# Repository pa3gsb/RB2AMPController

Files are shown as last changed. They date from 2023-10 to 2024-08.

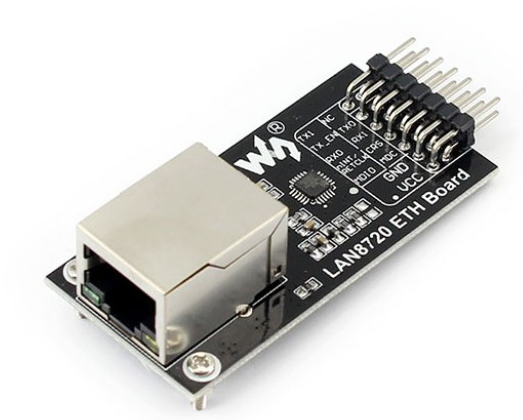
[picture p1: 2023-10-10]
hardware/image/lan8720.PNG

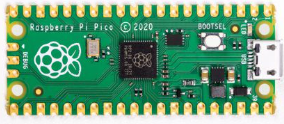
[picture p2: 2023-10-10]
hardware/image/rp2040.PNG

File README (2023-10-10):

# Radioberry AMP Controller Board by PA3GSB

RB2AMPController (Radioberry V2.0 Amplifier Controller)

The board contains an ethernet module and a Raspberry Pi Pico (RP2040) module which implemets a TCPIP server.

The radioberry firmware talks to the controller server using a TCPIP client.

The information in the openhpsdr protocol-1 is used to control the amplifier. So if you change the frequency in your favourite SDR program the LPF filter
in the AMP will be set. Also when going into transmit; the AMP will make use of a sequencer and will switch the relais in the right order.

Information of the AMP will be placed into the protocol and will be presented in the SDR program user interface to the operator.
Information here is the temperature of the AMP, the forward and reverse power.

This controller board supports works for now only with the radioberry juice board.

## RB2AMPController-Protocol

REQUEST (to server / AMP Controller)

indentification 4bytes:	0x00 0x00 0xef 0xfe 
byte 5:  	off 	0x00 
			standby 0x0f  
			active  0xff  
byte 6:  	PTT  	0x00 	PA off.
					0xFF  	PA on.
byte 7:  	lpf  	0x00 	no LPF filter.
					0x01 	160m
					0x02 	80m
					0x03 	60m
					0x04	40m
					0x05	20m
					0x06	10m
				
Total 20 bytes (so some spare bytes)

RESPONSE (from server / AMP Controller)

identification 	4bytes:	0x00 0x00 0xef 0xfe
byte 5:			versie pa firmware  (1/10 => 0.1)  divide by 10.
byte 6, 7		temp
byte 8, 9		forwrd pwr
byte 10,11		reverse pwr
byte 12,13		u   (not implemented) 
byte 14,15		i	(not implemented) 
byte 20			error  

Total 20 bytes (so some spare bytes)

## Firmware of the RB2AMPController
The RPI pico board contains a microcontroller which need a firmware.

For loading this firmware you need to connect a USB cable to the board.
Push the button on the Pico and then plug the USB cable into your PC.
The Pico will appear as a flash drive on the PC. Then copy the file xxx.uf2 to the Pico. 

The Pico will reboot and the Pico LED will flash slowly.

### adding descriptions per port.

### Fan Control
PWM controlled FAN

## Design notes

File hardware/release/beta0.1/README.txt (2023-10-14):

RB2AMPController beta 0.1 Release

## Project Description

RB2AMPController (Radioberry V2.0 Amplifier Controller)

This board will be part of an amplifier. 

The ethernet connection of the board does control the amplifier.

## Folders

- pcb 
	contains the gerber pcb files and drill file.
- position
	position files top and bottom
- bom
	contains the BOM.

## Assembly

no special info.
	
## More info

The Radioberry pico (RP2040) needs a firmware.

##Note

The schema does contain a 18 pin / 8 channel IO driver; but the footprint i selected was 16 pins. 

## Contact
Please contact Johan, PA3GSB pa3gsb@gmail.com with any questions.

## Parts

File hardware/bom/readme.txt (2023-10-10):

KICAD

kicad 7.0: C:\Program Files\KiCad\bin>xsltproc -o "C:/dev/git/RB2AMPController/RB2AMPController" "C:\Program Files\KiCad\bin\scripting\plugins\bom2csv.xsl" "C:\dev\git\RB2AMPController\RB2AMPController.xml"

schema editor -> generate bom  (use standaard bom2csv -> creates xml file)

use of python2.7: to install modules: C:\Python27\python -m pip install <module>

In the bom directory:

parts.json  ; selector + component data..

C:\Python27\python mkassemblybom.py

creates 

bompre.dat
bom.dat
bompost.dat

https://www.sharelatex.com  make an account

upload bom.tex and the dat files -> compile -> nice bom pdf.

prices:

read prices from octopart:

C:\Python27\python updateprices.py

generateds dat files..
C:\Python27\python mkstandardbom.py

upload bom.tex and the dat files -> compile -> nice price bom pdf.

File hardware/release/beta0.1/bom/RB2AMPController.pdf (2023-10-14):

## Radioberry-amp-controller beta0.1 BOM

Assembly Build - October 14, 2023

Line | Description | Part Number | Sub OK | Designators | Footprint | Pins | Quantity
| 100pF 0805NP0≥50V≤5% | CC0805JRNPO0BN101 (http://www.octopart.com/search?q=CC0805JRNPO0BN101) | N | C101,C105 | 0805 | 2 | 2
| 0.1uF 0805≥X5R≥50V≤20% | C0805C104K1RECAUTO (http://www.octopart.com/search?q=C0805C104K1RECAUTO) | Y | C102,C103,C106,C107, C201,C202,C204 | 0805 | 2 | 7
| 10uF 0805≥X5R≥6.3V≤20% | GRM21BR60J106ME19L (http://www.octopart.com/search?q=GRM21BR60J106ME19L) | Y | C104,C108 | 0805 | 2 | 2
| 1uF 0805≥X5R≥25V≤20% | CL21B105KAFNNNE (http://www.octopart.com/search?q=CL21B105KAFNNNE) | Y | C203 | 0805 | 2 | 1
| Schottky-diodes | BAT43W-G3-08 (http://www.octopart.com/search?q=BAT43W-G3-08) | Y | D201,D202,D203,D204, D205,D206 | 0805 | 2 | 6
| LED RA | LTST-S220KFKT (http://www.octopart.com/search?q=LTST-S220KFKT) | N | D207 | 2.1x1.0mmRightAngle | 2 | 1
| IC REG LINEAR 3.3V 800MA | LD1117S33TR (http://www.octopart.com/search?q=LD1117S33TR) | Y | IC101 | SOT223 | 4 | 1
| LDO-spanningregelaars 5.0V 0.8A Positive | NCP1117LPST50T3G, TS 1117 CW50 | N | IC102 | SOT223 | 4 | 1
| 100-ppm/ C precision microp-ower shunt voltage reference | LM4040DIM3X-3.0/NOPB (http://www.octopart.com/search?q=LM4040DIM3X-3.0/NOPB) | Y | IC301 | Custom | 3 | 1
| CONN HEADER VERT 2POS 2.54MM Würth Elektronik | 61300211121 (http://www.octopart.com/search?q=61300211121) | Y | J101 | Custom | 2 | 1
| CONN HEADER VERT 10POS 2.54MM Würth Elek-tronik | TMS-110-01-L-S-RA (http://www.octopart.com/search?q=TMS-110-01-L-S-RA) | Y | J201 | Custom | 10 | 1
| CONN HEADER VERT 2POS 2.54MM Würth Elektronik | 61300211121 (http://www.octopart.com/search?q=61300211121) | Y | J202 | Custom | 2 | 1
| CONN HEADER VERT 3POS 2.54MM Würth Elektronik | 61300311121 (http://www.octopart.com/search?q=61300311121) | Y | J203 | Custom | 3 | 1
| CONN HEADER VERT 4POS 2.54MM Würth Elektronik | 61300411121 (http://www.octopart.com/search?q=61300411121) | Y | J204 | Custom | 4 | 1
| CONN HEADER VERT 2POS 2.54MM Würth Elektronik | 61300211121 (http://www.octopart.com/search?q=61300211121) | Y | J205 | Custom | 2 | 1
| CONN HEADER VERT 2POS 2.54MM Würth Elektronik | 61300211121 (http://www.octopart.com/search?q=61300211121) | Y | J206 | Custom | 2 | 1
| 0Ohm 0805≤5%≥1/10W | RC0805JR-070RL (http://www.octopart.com/search?q=RC0805JR-070RL) | Y | J207,J208 | 0805 | 2 | 2
| CONN HEADER VERT 2POS 2.54MM Würth Elektronik | 61300211121 (http://www.octopart.com/search?q=61300211121) | Y | J209 | Custom | 2 | 1
| CONN HEADER VERT 3POS 2.54MM Würth Elektronik | 61300311121 (http://www.octopart.com/search?q=61300311121) | Y | J210 | Custom | 3 | 1

1

Line | Description | Part Number | Sub OK | Designators | Footprint | Pins | Quantity
| CONN HEADER VERT 2POS 2.54MM Würth Elektronik | 61300211121 (http://www.octopart.com/search?q=61300211121) | Y | J212 | Custom | 2 | 1
| CONN HDR 14POS 0.1 GOLD PCB R/A | SFH11-PBPC-D07-RA-BK (http://www.octopart.com/search?q=SFH11-PBPC-D07-RA-BK) | Y | J301 | Custom | 14 | 1
| MOSFET N-CH 60V 300mA | 2N7002K-T1-E3 (http://www.octopart.com/search?q=2N7002K-T1-E3) | N | Q201,Q202 | SOT-23-3 | 3 | 2
| 680 0805≤1%≥2/10W | 71-TNPW0805680RBEEA (http://www.octopart.com/search?q=71-TNPW0805680RBEEA) | Y | R101 | 0805 | 2 | 1
| 10K 0805≤5%≥1/10W | ?? (http://www.octopart.com/search?q=??) | Y | R201,R203,R207,R209, R214 | 0805 | 2 | 5
| 4.7K 0805≤1%≥2/10W | 71-TNPW08054K70BEEN (http://www.octopart.com/search?q=71-TNPW08054K70BEEN) | Y | R202,R204,R215,R216, R217,R218 | 0805 | 2 | 6
| 330K 0805≤1%≥2/10W | 71-71-TNPW0805330KBEEN (http://www.octopart.com/search?q=71-71-TNPW0805330KBEEN) | Y | R205 | 0805 | 2 | 1
| 1K 0805≤5%≥1/10W | RC0805FR-071KL (http://www.octopart.com/search?q=RC0805FR-071KL) | Y | R206 | 0805 | 2 | 1
| 20K 0805≤1%≥2/10W | 71-TNPW080520K0BEEN (http://www.octopart.com/search?q=71-TNPW080520K0BEEN) | Y | R208,R213 | 0805 | 2 | 2
| 50-V, 7-ch darlington array | ULN 2003D1013 | Y | U201 | Custom | 16 | 1
| Interface - I/O Expanders In/Out I2C int | MCP23008-E/SS (http://www.octopart.com/search?q=MCP23008-E/SS) | Y | U202 | Custom | 20 | 1
| RP2040-PICO-HDR (SBC) | RP2040-PICO-HDR (http://www.octopart.com/search?q=RP2040-PICO-HDR) | Y | U301 | Custom | 40 | 1

Line Items: SMT:23 Assembled TH:10
Parts: SMT:51 Assembled TH:10
Pins: SMT:143 Assembled TH:74
Do Not Assemble: C205 J211 Q203 Q204 R210 R211 R212

2

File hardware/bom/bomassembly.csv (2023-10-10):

"Part ID" | "Description" | "Part Number" | "Substitution
Okay" | "Designators" | "Footprint" | "Pins" | "Quantity" | "Part Reference Link"
14236 | "10uF 1206>=X5R>=25V<=20%" | "CL31A106KAHNNNE" | Y | "C101 | C102 | C110 | C113" | "1206" | 2 | 4 | "=HYPERLINK("http://www.octopart.com/search?q=CL31A106KAHNNNE")"
2131 | "4.7uF 0805>=X5R>=25V<=20%" | "GRM21BR61E475KA12L" | Y | "C103" | "0805" | 2 | 1 | "=HYPERLINK("http://www.octopart.com/search?q=GRM21BR61E475KA12L")"
55004 | "4.7nF 0603>=X5R>=25V<=20%" | "CL10B472KB8NNNC" | Y | "C104 | C201 | C203 | C207
C208" | "0603" | 2 | 5 | "=HYPERLINK("http://www.octopart.com/search?q=CL10B472KB8NNNC")"
46786 | "22uF 0805>=X5R>=16V<=20%" | "CL21A226MOCLRNC" | Y | "C105 | C106 | C107 | C108
C109 | C305" | "0805" | 2 | 6 | "=HYPERLINK("http://www.octopart.com/search?q=CL21A226MOCLRNC")"
29074 | "1uF 0805>=X5R>=25V<=20%" | "CL21B105KAFNNNE" | Y | "C111 | C306 | C307 | C308
C309" | "0805" | 2 | 5 | "=HYPERLINK("http://www.octopart.com/search?q=CL21B105KAFNNNE")"
15331 | "0.1uF 0603>=X5R>=50V<=20%" | "C0603C104M5RACTU" | Y | "C112 | C114 | C117" | "0603" | 2 | 3 | "=HYPERLINK("http://www.octopart.com/search?q=C0603C104M5RACTU")"
1940 | "1nF 0603>=X5R>=50V<=20%" | "C0603C102M5RACTU" | Y | "C115 | C123" | "0603" | 2 | 2 | "=HYPERLINK("http://www.octopart.com/search?q=C0603C102M5RACTU")"
58143 | "10nF 0603>=X5R>=50V<=20%" | "C0603C103M5RACTU" | Y | "C116" | "0603" | 2 | 1 | "=HYPERLINK("http://www.octopart.com/search?q=C0603C103M5RACTU")"
 | "100uF 1206>=X5R>=6.3V<=20%" | "GRM31CR60J107ME39K" | Y | "C118" | "1206" | 2 | 1 | "=HYPERLINK("http://www.octopart.com/search?q=GRM31CR60J107ME39K")"
 | "10pF 0805NP0>=50V<=5%" | "CC0805JRNPO9BN100" | Y | "C119 | C121" | "0805" | 2 | 2 | "=HYPERLINK("http://www.octopart.com/search?q=CC0805JRNPO9BN100")"
 | "100pF 0603NP0>=50V<=5%" | "CC0603JRNPO0BN101" | N | "C120 | C122" | "0603" | 2 | 2 | "=HYPERLINK("http://www.octopart.com/search?q=CC0603JRNPO0BN101")"
15331 | "0.1uF 0603>=X5R>=50V<=20%" | "C0603C104M5RACTU" | Y | "C202 | C206 | C209 | C303
C304 | C311 | C313 | C314
C315 | C316 | C317 | C318
C319 | C320 | C321 | C322
C323" | "0603" | 2 | 17 | "=HYPERLINK("http://www.octopart.com/search?q=C0603C104M5RACTU")"
16531 | "1uF 0603>=X5R>=6.3V<=20%" | "GRM188R61E105KA12D" | Y | "C204 | C205 | C210 | C211" | "0603" | 2 | 4 | "=HYPERLINK("http://www.octopart.com/search?q=GRM188R61E105KA12D")"
29074 | "1uF 0805>=X5R>=25V<=20%" | "CL21B105KAFNNNE" | Y | "C301 | C302" | "0805" | 2 | 2 | "=HYPERLINK("http://www.octopart.com/search?q=CL21B105KAFNNNE")"
2142 | "100pF 0805NP0>=50V<=5%" | "CC0805JRNPO0BN101" | N | "C310" | "0805" | 2 | 1 | "=HYPERLINK("http://www.octopart.com/search?q=CC0805JRNPO0BN101")"
 | "390pF 0805NP0>=50V<=5%" | "CC0805JRNPO0BN391" | Y | "C312" | "0805" | 2 | 1 | "=HYPERLINK("http://www.octopart.com/search?q=CC0805JRNPO0BN391")"
 | "Power" | "PJ-102AH" | Y | "CN101" | "Custom" | 3 | 1 | "=HYPERLINK("http://www.aliexpress.com/wholesale?SearchText=DIKAVS DC005")"
 | "TVS Diode" | "SMBJ18CA" | N | "D101" | "DO-214AA (SMB)" | 2 | 1 | "=HYPERLINK("http://www.aliexpress.com/wholesale?SearchText=SMBJ18CA")"
9999 | "1uF 0805>=X5R>=25V<=20%" | "CL21B105KAFNNNE" | Y | "DB201 | DB202" | "0805" | 2 | 2 | "=HYPERLINK("http://www.octopart.com/search?q=CL21B105KAFNNNE")"
 | "2x5 M 0.1in" | "67997-410HLF" | Y | "DB203" | "Custom" | 10 | 1 | "=HYPERLINK("http://www.octopart.com/search?q=67997-410HLF")"
 | "FUSE PTC 3.0A 24V" | "MF-LSMF300/24X-2" | N | "F101" | "2920 7.36x5.12mm" | 2 | 1 | "=HYPERLINK("http://www.aliexpress.com/wholesale?SearchText=MF-LSMF300/24X-2")"
 | "FB 0603 >=600R@100MHz <=200mOhm@DC 1A <=25%" | "MPZ1608S601ATA00" | Y | "FB101 | FB102 | FB201" | "0603" | 2 | 3 | "=HYPERLINK("http://www.octopart.com/search?q=MPZ1608S601ATA00")"
 | "IC REG LINEAR 3.3V 800MA" | "LD1117S33TR" | Y | "IC101" | "SOT223" | 4 | 1 | "=HYPERLINK("http://www.octopart.com/search?q=LD1117S33TR")"
21903 | "0Ohm 0603<=5%>=1/10W" | "RC0603JR-070RL" | Y | "J201 | J202 | J203 | J204
J205 | J206 | J207 | J301
J302" | "0603" | 2 | 9 | "=HYPERLINK("http://www.octopart.com/search?q=RC0603JR-070RL")"
 | "20 Positions Header Connector (2.54mm)" | "76342-310LF" | Y | "JP201" | "2x10" | 20 | 1 | "=HYPERLINK("http://www.octopart.com/search?q=76342-310LF")"
 | "Relay" | "EC2-3NU" | Y | "K301" | "Custom" | 10 | 1 | "=HYPERLINK("http://www.octopart.com/search?q=EC2-3NU")"
 | "3.3uH >=2.4A" | "SRR4528A-3R3Y" | N | "L101" | "5x5mm" | 2 | 1 | "=HYPERLINK("http://www.octopart.com/search?q=SRR4528A-3R3Y")"
 | "MOSFET P-CH 30V" | "DMP3099L-7" | N | "Q101" | "SOT-23-3" | 3 | 1 | "=HYPERLINK("http://www.octopart.com/search?q=DMP3099L-7")"
 | "Thermal Sensor" | "MCP9700T-E/TT" | N | "Q201" | "SOT-23-3" | 3 | 1 | "=HYPERLINK("http://www.aliexpress.com/wholesale?SearchText=MCP9700T-E/TT")"
 | "Inductive Load Driver" | "NUD3124LT1G" | N | "Q202 | Q203" | "SOT-23-3" | 3 | 2 | "=HYPERLINK("http://www.aliexpress.com/wholesale?SearchText=NUD3124LT1G")"
 | "RF LDMOS" | "AFT05MS003NT1" | N | "Q301 | Q302" | "SOT-89-3" | 3 | 2 | "=HYPERLINK("http://www.octopart.com/search?q=AFT05MS003NT1")"
26547 | "10K 0603<=5%>=1/10W" | "RC0603FR-0710KL" | Y | "R101 | R214 | R215" | "0603" | 2 | 3 | "=HYPERLINK("http://www.octopart.com/search?q=RC0603FR-0710KL")"
 | "16.2K 0603<=1%>=1/10W" | "RC0603FR-0716K2L" | Y | "R102" | "0603" | 2 | 1 | "=HYPERLINK("http://www.octopart.com/search?q=RC0603FR-0716K2L")"
 | "1.8K 0603<=1%>=1/10W" | "RC0603FR-071K8L" | Y | "R103" | "0603" | 2 | 1 | "=HYPERLINK("http://www.octopart.com/search?q=RC0603FR-071K8L")"
 | "4.7K 0603<=5%>=1/10W" | "RC0603FR-074K7L" | Y | "R104" | "0603" | 2 | 1 | "=HYPERLINK("http://www.octopart.com/search?q=RC0603FR-074K7L")"
4597 | "2.2K 0603<=5%>=1/10W" | "RC0603FR-072K2L" | Y | "R201 | R202 | R217 | R218" | "0603" | 2 | 4 | "=HYPERLINK("http://www.octopart.com/search?q=RC0603FR-072K2L")"
21904 | "1K 0603<=5%>=1/10W" | "RC0603FR-071KL" | Y | "R203 | R206 | R208 | R209" | "0603" | 2 | 4 | "=HYPERLINK("http://www.octopart.com/search?q=RC0603FR-071KL")"
23502 | "100 0603<=1%>=1/10W" | "RC0603FR-07100RL" | Y | "R204 | R207 | R220 | R221" | "0603" | 2 | 4 | "=HYPERLINK("http://www.octopart.com/search?q=RC0603FR-07100RL")"
23693 | "270 0603<=5%>=1/10W" | "RC0603FR-07270RL" | Y | "R205 | R304 | R311" | "0603" | 2 | 3 | "=HYPERLINK("http://www.octopart.com/search?q=RC0603FR-07270RL")"
23694 | "27K 0603<=1%>=1/10W" | "RC0603FR-0727KL" | Y | "R210 | R211" | "0603" | 2 | 2 | "=HYPERLINK("http://www.octopart.com/search?q=RC0603FR-0727KL")"
23987 | "9.1K 0603<=1%>=1/10W" | "RC0603FR-079K1L" | Y | "R212 | R213" | "0603" | 2 | 2 | "=HYPERLINK("http://www.octopart.com/search?q=RC0603FR-079K1L")"
23889 | "4.7K 0603<=5%>=1/10W" | "RC0603FR-074K7L" | Y | "R216 | R219" | "0603" | 2 | 2 | "=HYPERLINK("http://www.octopart.com/search?q=RC0603FR-074K7L")"
 | "10K 0805<=5%>=1/10W" | "??" | Y | "R301 | R302" | "0805" | 2 | 2 | "=HYPERLINK("http://www.octopart.com/search?q=??")"
 | "0.04 1206<=1%>=1/4W" | "RL1206FR-070R04L" | Y | "R303" | "1206" | 2 | 1 | "=HYPERLINK("http://www.octopart.com/search?q=RL1206FR-070R04L")"
18201 | "1K 0805<=5%>=1/10W" | "RC0805FR-071KL" | Y | "R305 | R308" | "0805" | 2 | 2 | "=HYPERLINK("http://www.octopart.com/search?q=RC0805FR-071KL")"
 | "12 0805<=5%>=1/8W" | "RC0805FR-0712RL" | Y | "R306 | R312" | "0805" | 2 | 2 | "=HYPERLINK("http://www.octopart.com/search?q=RC0805FR-0712RL")"
 | "5.9 0805<=0.1%>=1/8W" | "RMCF0805FT5R90" | Y | "R307" | "0805" | 2 | 1 | "=HYPERLINK("http://www.octopart.com/search?q=RMCF0805FT5R90")"
 | "866 0805<=0.1%>=1/8W" | "RP73PF2A866RBTDF" | Y | "R309 | R310" | "0805" | 2 | 2 | "=HYPERLINK("http://www.octopart.com/search?q=RP73PF2A866RBTDF")"
 | "SMA Straight" | "5-1814832-1" | Y | "RF301 | RF302 | RF303" | "Custom" | 5 | 3 | "=HYPERLINK("http://www.octopart.com/search?q=5-1814832-1")"
 | "4:1 RF Transformer" | "B62152A4X30" | Y | "T301" | "Custom" | 4 | 1 | "=HYPERLINK("http://www.octopart.com/search?q=B62152A4X30")"
 | "1:1 RF Transformer" | "MABAES0060" | N | "T302" | "SM-22-5 3.81x3.81mm" | 5 | 1 | "=HYPERLINK("http://www.aliexpress.com/wholesale?SearchText=MABAES0060")"
 | "Switching Regulator" | "ST1S10PHR" | N | "U101" | "8-SOIC (3.90mm) EP" | 8 | 1 | "=HYPERLINK("http://www.aliexpress.com/wholesale?SearchText=st1s10")"
 | "LDO 10V 150mA" | "LP2985-10DBVR" | N | "U102" | "SOT-23-5" | 5 | 1 | "=HYPERLINK("http://www.octopart.com/search?q=LP2985-10DBVR")"
 | "Slow ADC" | "MAX11613EUA" | N | "U201" | "8-MSOP (3.00mm)" | 8 | 1 | "=HYPERLINK("http://www.octopart.com/search?q=MAX11613EUA")"
 | "Digital Rheostat 5K" | "MCP4662-502E/UN" | N | "U202" | "10-MSOP (3.00mm)" | 10 | 1 | "=HYPERLINK("http://www.octopart.com/search?q=MCP4662-502E/UN")"
 | "Current Sense AMP" | "INA199A1DC" | N | "U301" | "SC-70-6" | 6 | 1 | "=HYPERLINK("http://www.octopart.com/search?q=INA199A1DC")"
 | "21cm PFTE silver plated 24to30AWG wire" | "400R0111-24-9" | N | "W301" | "Custom" | 0 | 1 | "=HYPERLINK("http://www.aliexpress.com/wholesale?SearchText=PFTE Teflon Silver Plated Wire 30AWG")"
"Line Items SMT:" | " " | 50 | "Line Items TH:" | " " | 5
"Parts SMT:" | " " | 124 | "Parts TH:" | " " | 5
"Pins SMT:" | " " | 286 | "Pins TH:" | " " | 43

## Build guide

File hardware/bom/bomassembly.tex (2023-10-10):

\documentclass{article} 
\usepackage[english]{babel}
\usepackage[bookmarks=false]{hyperref}
\usepackage{pdflscape}
\usepackage{xcolor}
\usepackage{longtable}
\usepackage[T1]{fontenc}
\hypersetup{
    colorlinks,
    linkcolor={red!50!black},
    citecolor={blue!50!black},
    urlcolor={blue!80!black}
}
\usepackage[letterpaper, landscape, left=1.3cm, right=1.3cm, top=2cm, bottom=2.5cm]{geometry}

\begin{document}

\input{bompre.dat}

\begin{center}
    \begin{longtable}{| r | p{4.7cm} | p{3.8cm} | l | p{3.8cm} | l | r | r |}
    \hline
	\multicolumn{1}{|l|}{\textbf{Line}} & \multicolumn{1}{l|}{\textbf{Description}} & \multicolumn{1}{l|}{\textbf{Part Number}} & \multicolumn{1}{l|}{\textbf{Sub OK}} & \multicolumn{1}{l|}{\textbf{Designators}} & \multicolumn{1}{l|}{\textbf{Footprint}} & \multicolumn{1}{r|}{\textbf{Pins}} & \multicolumn{1}{r|}{\textbf{Quantity}} \\ \hline	 
	\endhead
	\input{bom.dat}
    \end{longtable}
\end{center}
\input{bompost.dat}
\end{document}

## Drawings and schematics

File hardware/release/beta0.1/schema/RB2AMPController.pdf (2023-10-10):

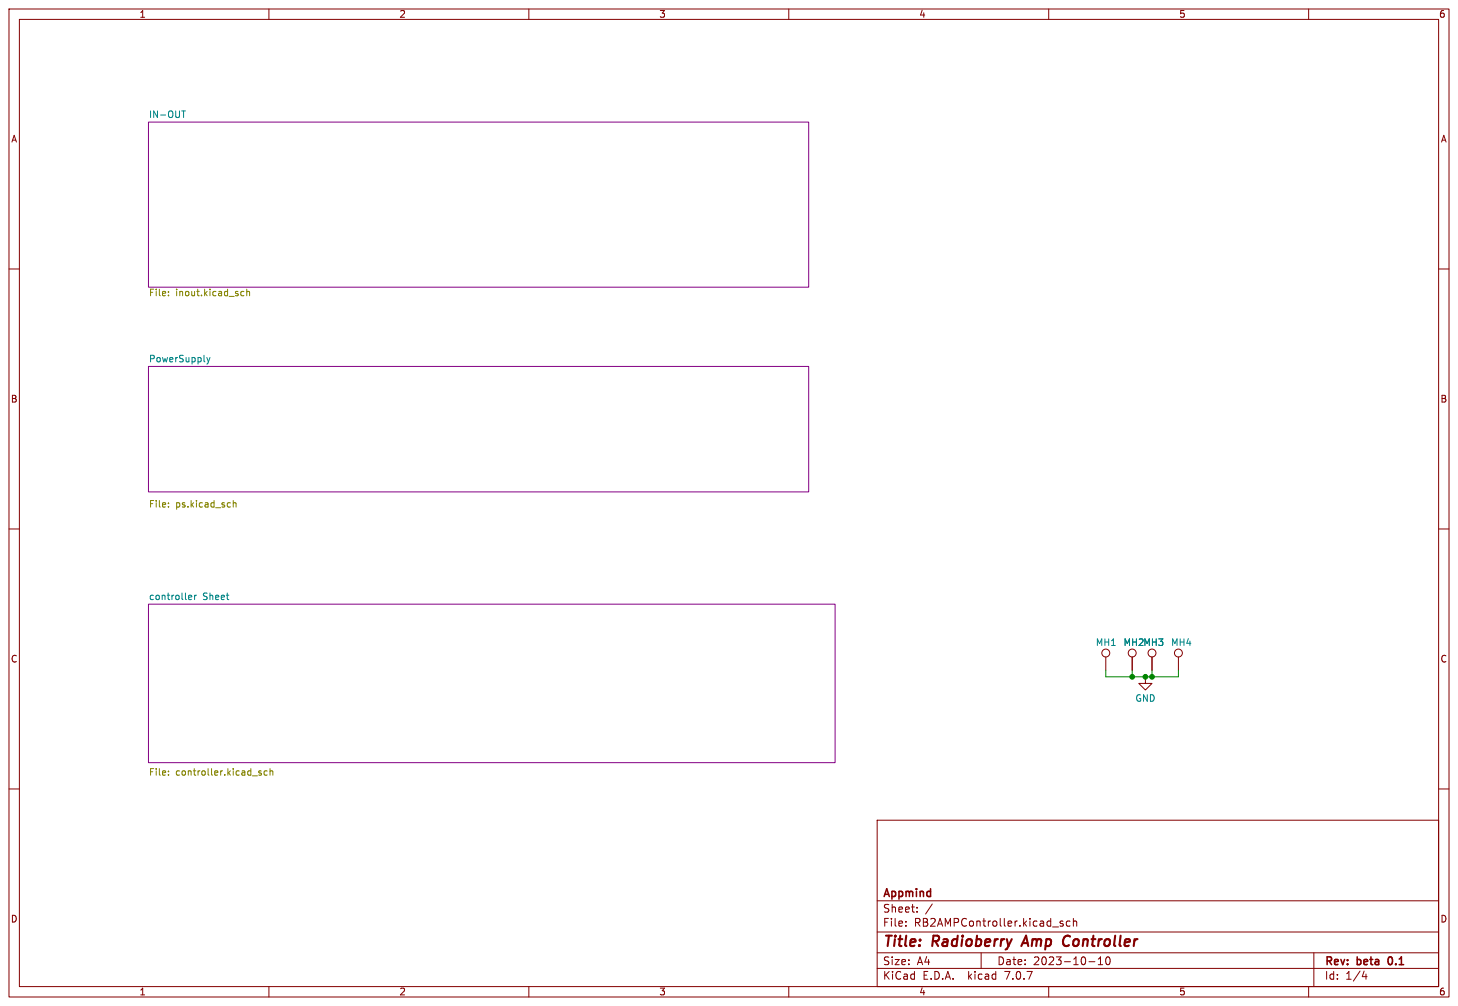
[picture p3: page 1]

Id: 1/4 Title: Radioberry Amp Controller File: RB2AMPController.kicad_sch Sheet: / Appmind

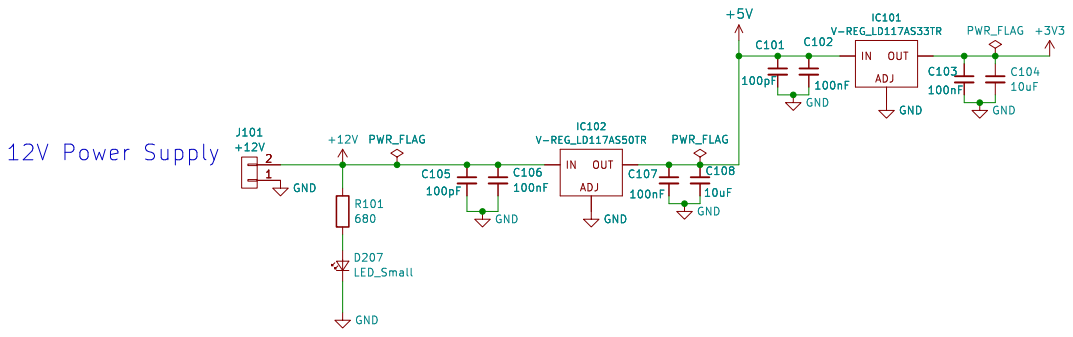
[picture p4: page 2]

Id: 2/4 Title: File: ps.kicad_sch Sheet: /PowerSupply/

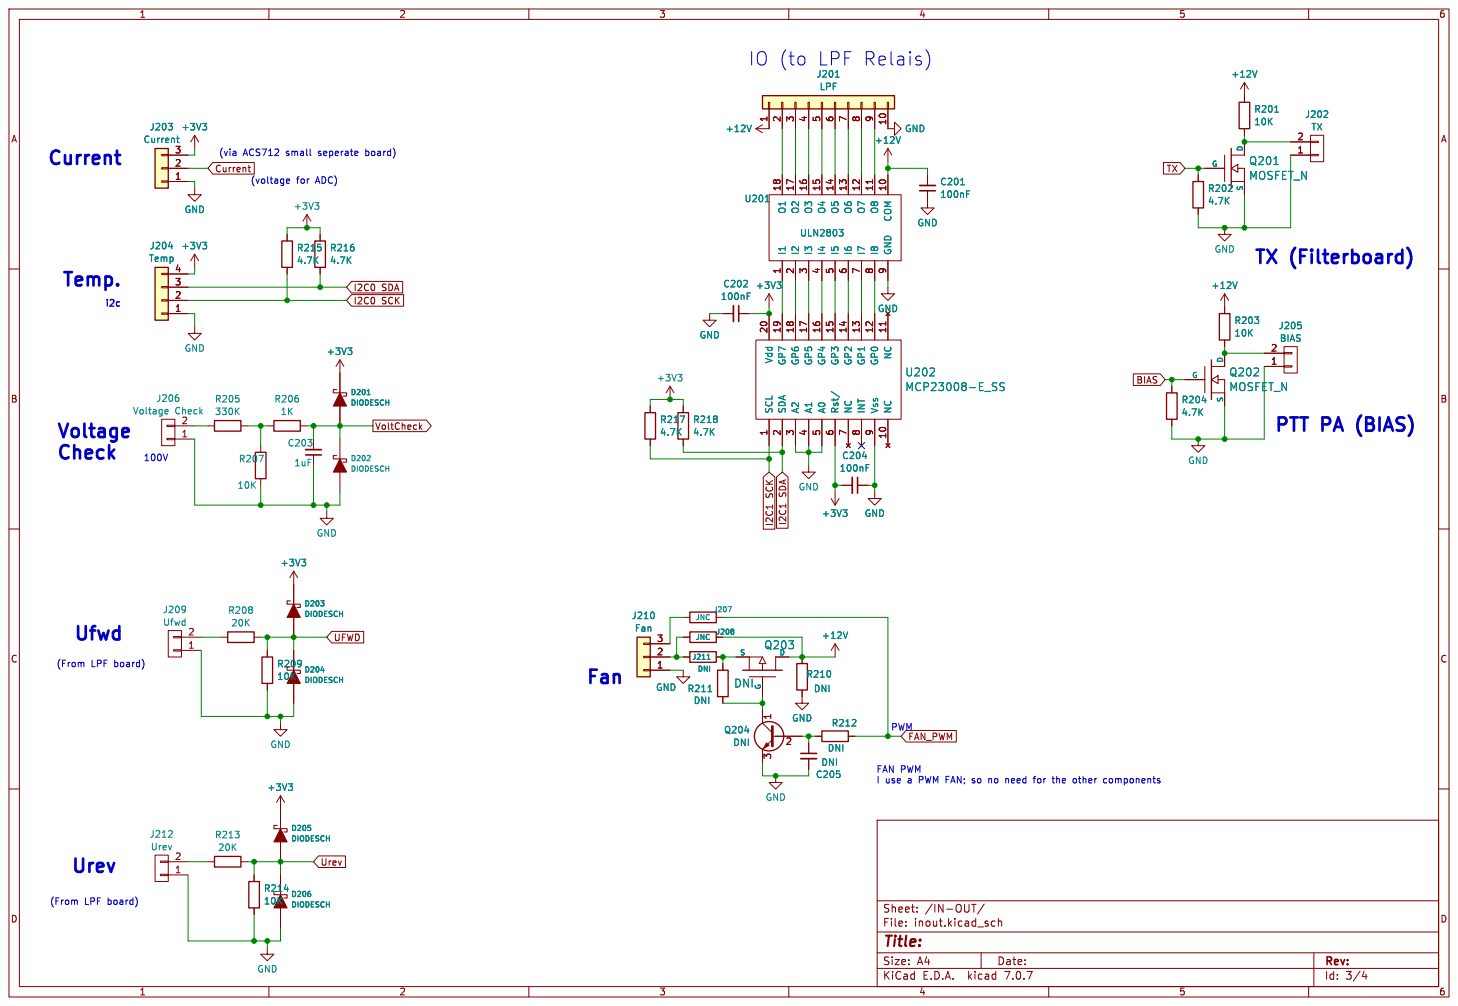
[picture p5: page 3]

IO (to LPF Relais)

(via ACS712 small seperate board)

FAN PWM
I use a PWM FAN; so no need for the other components

Id: 3/4 Title: File: inout.kicad_sch Sheet: /IN-OUT/ D206 DIODESCH

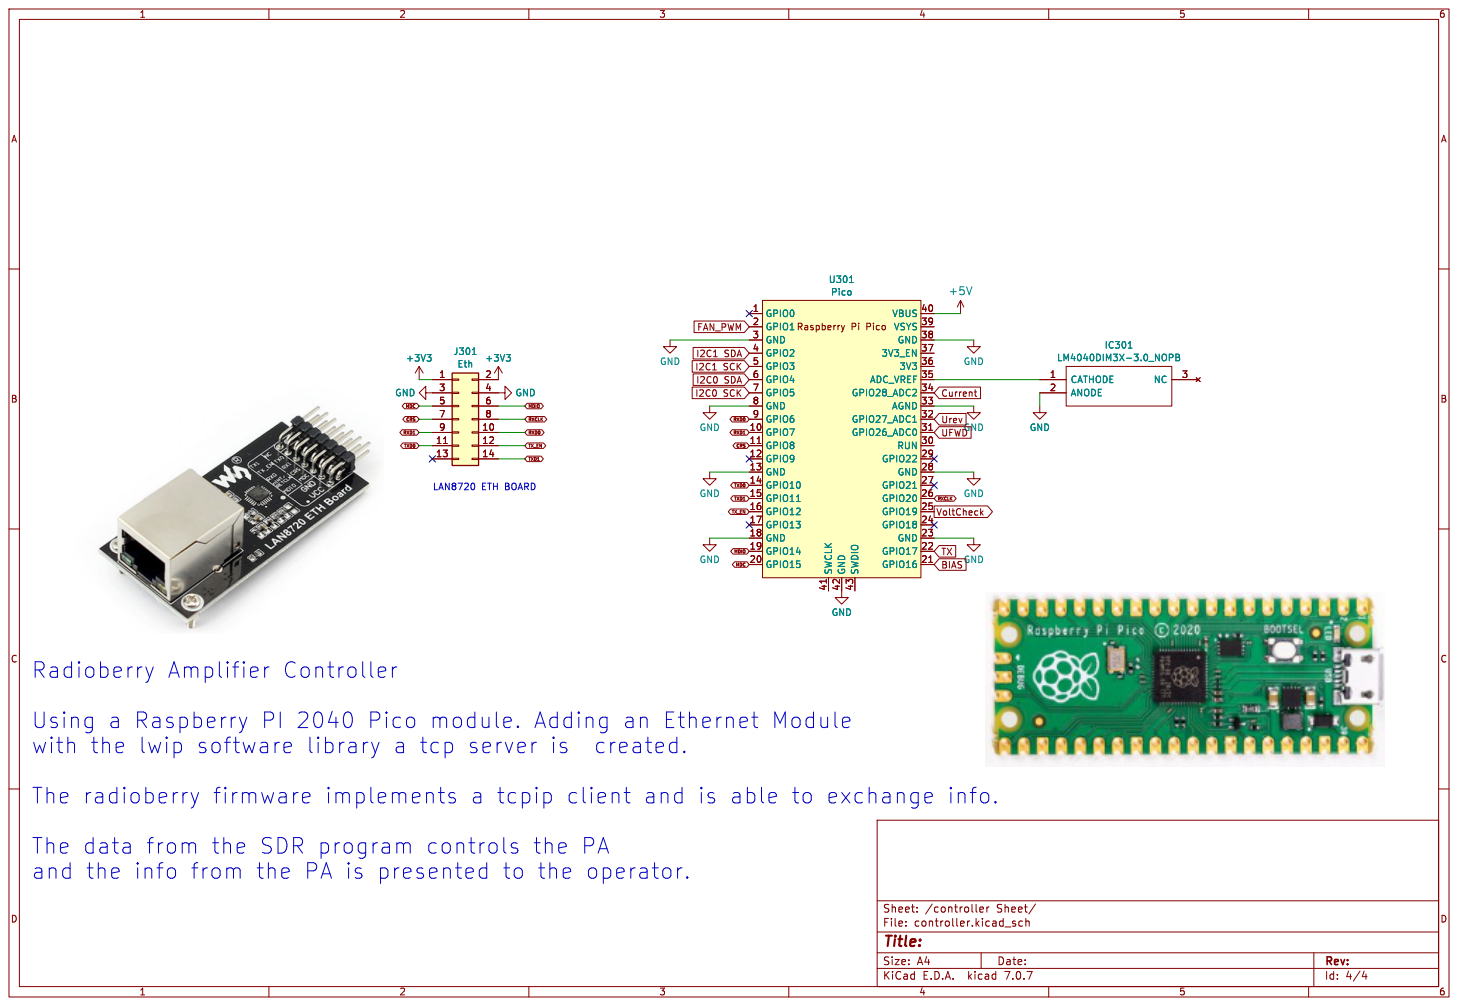
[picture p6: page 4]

RXD1 RXD0 LAN8720 ETH BOARD Radioberry Amplifier Controller

Using a Raspberry PI 2040 Pico module. Adding an Ethernet Module
with the lwip software library a tcp server is created.

The data from the SDR program controls the PA

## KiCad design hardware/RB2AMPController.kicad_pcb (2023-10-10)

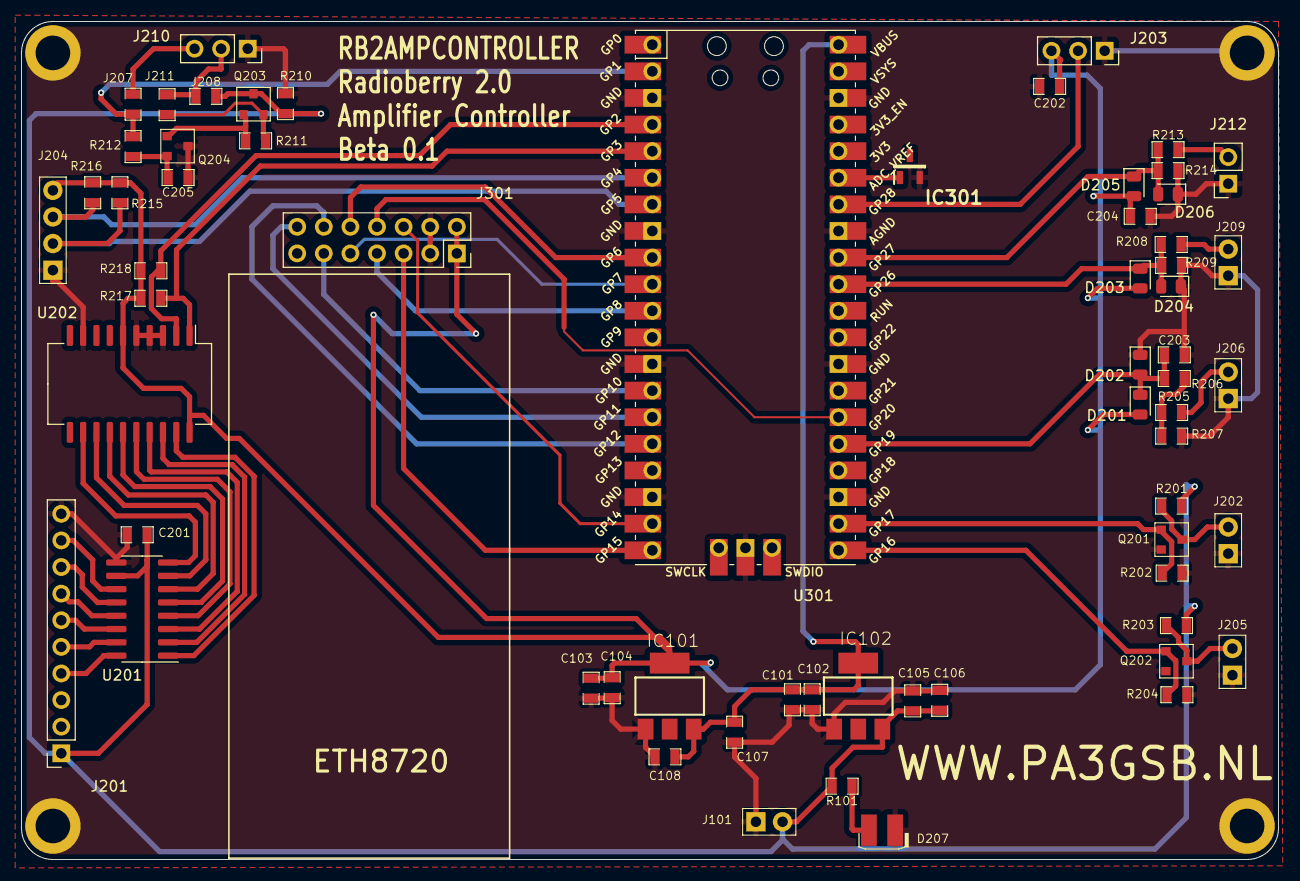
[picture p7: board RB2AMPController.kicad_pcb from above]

Board: 2 copper layers, 120.0 x 80.0 mm, 67 parts (0 on the bottom side), 51 nets.

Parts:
C101, C105: 100pF; SMD-0805
C102, C103, C106, C107, C201, C202, C204: 100nF; SMD-0805
C104, C108: 10uF; SMD-0805
C203: 1uF; SMD-0805
C205: DNI; SMD-0805
D201, D202, D203, D204, D205, D206: DIODESCH; D_0805_2012Metric
D207: LED_Small; LED
IC101: V-REG_LD117AS33TR; V-REG_SOT223
IC102: V-REG_LD117AS50TR; V-REG_SOT223
IC301: LM4040DIM3X-3.0_NOPB; SOT95P237X112-3N
J101: +12V; 2x1
J201: LPF; PinSocket_1x10_P2.54mm_Vertical
J202: TX; 2x1
J203: Current; PinSocket_1x03_P2.54mm_Vertical
J204: Temp; 4x1
J205: BIAS; 2x1
J206: Voltage Check; 2x1
J207, J208: JNC; SMD-0805
J209: Ufwd; 2x1
J210: Fan; PinSocket_1x03_P2.54mm_Vertical
J211: DNI; SMD-0805
J212: Urev; PinSocket_1x02_P2.54mm_Vertical
J301: Eth; PinSocket_2x07_P2.54mm_Vertical
MH1, MH2, MH3, MH4: DNI; m3
Q201, Q202: MOSFET_N; SOT23_3
Q203, Q204: DNI; SOT23_3
R101: 680; SMD-0805
R201, R203, R207, R209, R214: 10K; SMD-0805
R202, R204, R215, R216, R217, R218: 4.7K; SMD-0805
R205: 330K; SMD-0805
R206: 1K; SMD-0805
R208, R213: 20K; SMD-0805
R210, R211, R212: DNI; SMD-0805
U201: ULN2803; SOIC-16_3.9x9.9mm_P1.27mm
U202: MCP23008-E_SS; SOIC-20W_7.5x15.4mm_P1.27mm
U301: Pico; RPi_Pico_SMD_TH

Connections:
+3V3: C103.1, C104.1, C202.1, C204.2, D201.2 (K), D203.2 (K), D205.2 (K), IC101.4 (OUT), J203.3, J204.4, J301.1, J301.2, R215.2, R216.2, R217.2, R218.2, U202.6 (Rst/), U202.20 (Vdd)
+5V: C101.1, C102.1, C107.1, C108.1, IC101.3 (IN), IC102.4 (OUT), U301.40 (VBUS)
+12V: C105.1, C106.1, C201.2, IC102.3 (IN), J101.2, J201.1, J208.1, Q203.3 (D), R101.1, R201.2, R203.2, R210.1, U201.10 (COM)
BIAS: Q202.1 (G), R204.2, U301.21 (GPIO16)
CRS: J301.7, U301.11 (GPIO8)
Current: J203.2, U301.34 (GPIO28_ADC2)
FAN_PWM: J207.1, R212.2, U301.2 (GPIO1)
GND: C101.2, C102.2, C103.2, C104.2, C105.2, C106.2, C107.2, C108.2, C201.1, C202.2, C203.1, C204.1, C205.2, D202.1 (A), D204.1 (A), D206.1 (A), D207.1 (K), IC101.1 (ADJ), IC102.1 (ADJ), IC301.2 (ANODE), J101.1, J201.10, J202.1, J203.1, J204.1, J205.1, J206.1, J209.1, J210.1, J212.1, J301.3, J301.4, MH1.1, MH2.1, MH3.1, MH4.1, Q201.2 (S), Q202.2 (S), Q204.3 (E), R202.1, R204.1, R207.1, R209.2, R210.2, R214.2, U201.9 (GND), U202.3 (A2), U202.4 (A1), U202.5 (A0), U202.9 (Vss), U301.3 (GND), U301.8 (GND), U301.13 (GND), U301.18 (GND), U301.23 (GND), U301.28 (GND), U301.33 (AGND), U301.38 (GND), U301.42 (GND)
I2C0 SCK: J204.2, R215.1, U301.7 (GPIO5)
I2C0 SDA: J204.3, R216.1, U301.6 (GPIO4)
I2C1 SCK: R217.1, U202.1 (SCL), U301.5 (GPIO3)
I2C1 SDA: R218.1, U202.2 (SDA), U301.4 (GPIO2)
MDC: J301.5, U301.20 (GPIO15)
MDIO: J301.6, U301.19 (GPIO14)
unnamed: D207.2 (A), R101.2
unnamed: IC301.1 (CATHODE), U301.35 (ADC_VREF)
unnamed: J201.4, U201.16 (O3)
unnamed: J201.5, U201.15 (O4)
unnamed: J201.6, U201.14 (O5)
unnamed: J201.7, U201.13 (O6)
unnamed: J201.8, U201.12 (O7)
unnamed: J201.9, U201.11 (O8)
unnamed: J202.2, Q201.3 (D), R201.1
unnamed: J205.2, Q202.3 (D), R203.1
unnamed: J206.2, R205.1
unnamed: J209.2, R208.1
unnamed: J208.2, J210.2, J211.1
unnamed: J207.2, J210.3
unnamed: J212.2, R213.1
unnamed: Q203.1 (G), Q204.1 (C), R211.2
unnamed: J211.2, Q203.2 (S), R211.1
unnamed: C205.1, Q204.2 (B), R212.1
unnamed: R205.2, R206.1, R207.2
unnamed: U201.1 (I1), U202.19 (GP7)
unnamed: U201.2 (I2), U202.18 (GP6)
unnamed: U201.3 (I3), U202.17 (GP5)
unnamed: U201.4 (I4), U202.16 (GP4)
unnamed: U201.5 (I5), U202.15 (GP3)
unnamed: U201.6 (I6), U202.14 (GP2)
unnamed: U201.7 (I7), U202.13 (GP1)
unnamed: U201.8 (I8), U202.12 (GP0)
RXCLK: J301.8, U301.26 (GPIO20)
RXD0: J301.10, U301.9 (GPIO6)
RXD1: J301.9, U301.10 (GPIO7)
TX: Q201.1 (G), R202.2, U301.22 (GPIO17)
TXD0: J301.11, U301.14 (GPIO10)
TXD1: J301.14, U301.15 (GPIO11)
TX_EN: J301.12, U301.16 (GPIO12)
UFWD: D203.1 (A), D204.2 (K), R208.2, R209.1, U301.31 (GPIO26_ADC0)
Urev: D205.1 (A), D206.2 (K), R213.2, R214.1, U301.32 (GPIO27_ADC1)
VoltCheck: C203.2, D201.1 (A), D202.2 (K), R206.2, U301.25 (GPIO19)

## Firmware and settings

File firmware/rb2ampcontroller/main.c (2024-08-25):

/*
 *
 */

#include "pico/stdlib.h"
#include "pico/multicore.h"
#include "hardware/clocks.h"
#include "lwip/dhcp.h"
#include "lwip/init.h"
#include "lwip/apps/httpd.h"
#include "rmii_ethernet/netif.h"
#include "lwip/ip4_addr.h"
#include "lwip/tcp.h"
#include "lwip/api.h"
#include "string.h"

#include "pico/binary_info.h"
#include "hardware/i2c.h"
#include "hardware/adc.h"
#include "hardware/pwm.h"

#define VERSION  0x01

#ifndef PICO_I2C0_SDA_PIN
#define PICO_I2C0_SDA_PIN 2
#endif
#ifndef PICO_I2C0_SCL_PIN
#define PICO_I2C0_SCL_PIN 3
#endif

const uint LED_PIN = PICO_DEFAULT_LED_PIN;
const uint BIAS_PIN = 16U;
const uint RELAIS_PIN = 17U;
const uint PWM_PIN = 1;

const uint PWM_FREQ = 30000; //3KHz

#define TCP_PORT 4242
#define DEBUG_printf printf
#define BUF_SIZE 20
#define POLL_TIME_S 5

uint16_t forward_adc_value = 0;
uint16_t reverse_adc_value = 0;

uint16_t pa_temparature = 0;   // temperature in celcius.
bool pa_temp_measure_error = false;

enum PowerState {
    OFF = 0x00,
    STANDBY = 0x0f,
    ACTIVE = 0xff
};

enum PowerState deviceState = OFF;

enum PowerState convertToPowerState(unsigned char stateValue) {
    switch (stateValue) {
        case OFF:
            return OFF;
        case STANDBY:
            return STANDBY;
        case ACTIVE:
            return ACTIVE;
        default:
            return OFF; // Return a default value or handle error
    }
}

enum LPFFilter {
    NO_LPF      = 0x00,
    LPF_160M    = 0x80,
    LPF_80M     = 0x40,
    LPF_60M     = 0x20,
    LPF_40M     = 0x10,
    LPF_20M     = 0x08,
    LPF_10M     = 0x04
};

enum LPFFilter lpfFilter = NO_LPF;

enum LPFFilter convertToLPFFilter(unsigned char filterValue) {
    switch (filterValue) {
        case NO_LPF:
            return NO_LPF;
        case LPF_160M:
            return LPF_160M;
        case LPF_80M:
            return LPF_80M;
        case LPF_60M:
            return LPF_60M;
        case LPF_40M:
            return LPF_40M;
        case LPF_20M:
            return LPF_20M;
        case LPF_10M:
            return LPF_10M;
        default:
            return NO_LPF; // Return a default value or handle error
    }
}

enum PTTState {
    PA_OFF = 0x00,
    PA_ON = 0xFF
};

enum PTTState pttState = PA_OFF;

enum PTTState convertToPTTState(unsigned char pttValue) {
    switch (pttValue) {
        case PA_OFF:
            return PA_OFF;
        case PA_ON:
            if (deviceState == ACTIVE) return PA_ON; else return PA_OFF;
        default:
            return PA_OFF; // Return a default value or handle error
    }
}

enum ActualTxState {
    TX_OFF          = 0x01,
    TX_ON           = 0x10
};

enum ActualTxState actualAmpState = TX_OFF;


void read_adc_values() {
    //read forward power
    adc_select_input(0);
    forward_adc_value = adc_read(); // Read the ADC value
    //DEBUG_printf("Forward ADC value is %d \n", forward_adc_value);

    //read reverse power
    adc_select_input(1);
    reverse_adc_value = adc_read(); // Read the ADC value
    //DEBUG_printf("Reverse ADC value is %d \n", reverse_adc_value);
}

/*
    Define constants for MCP9808

    http://adafru.it/1782

    i2c address 0x18
*/

#define MCP9808_ADDR 0x18
const uint8_t REG_TEMP_CRIT = 0x04;
const uint8_t REG_TEMP_AMB = 0x05;
const uint8_t REG_RESOLUTION = 0x08;

int mcp9808_init(void) {

    i2c_init(i2c0, 400 * 1000);
    gpio_set_function(PICO_DEFAULT_I2C_SDA_PIN, GPIO_FUNC_I2C);
    gpio_set_function(PICO_DEFAULT_I2C_SCL_PIN, GPIO_FUNC_I2C);
    gpio_pull_up(PICO_DEFAULT_I2C_SDA_PIN);
    gpio_pull_up(PICO_DEFAULT_I2C_SCL_PIN);

    bi_decl(bi_2pins_with_func(PICO_DEFAULT_I2C_SDA_PIN, PICO_DEFAULT_I2C_SCL_PIN,  GPIO_FUNC_I2C));
}


float mcp9808_convert_temp(uint8_t upper_byte, uint8_t lower_byte) {

    float temperature;

    //Check if TA <= 0°C and convert to denary accordingly
    if ((upper_byte & 0x10) == 0x10) {
        upper_byte = upper_byte & 0x0F;
        temperature = 256 - (((float) upper_byte * 16) + ((float) lower_byte / 16));
    } else {
        temperature = (((float) upper_byte * 16) + ((float) lower_byte / 16));
    }
    return temperature;
}


bool mcp9808_readtemperature(void) {

    uint8_t buf[2];
    uint16_t upper_byte;
    uint16_t lower_byte;

    float temperature;

    int result = i2c_write_timeout_us(i2c_default, MCP9808_ADDR, &REG_TEMP_AMB, 1, true, 1000);
    if (result == PICO_ERROR_GENERIC) {
        printf("failure in connecting / writing to temperature sensor\n"); 
        return false;
    } 
    if (result == PICO_ERROR_TIMEOUT) {
        printf("timeout in writing to temperature sensor\n"); 
        return false;
    } 

    result = i2c_read_timeout_us(i2c_default, MCP9808_ADDR, buf, 2, false, 1000);
    if (result == PICO_ERROR_GENERIC ) {
        printf("failure in connecting / reading temperature sensor\n"); 
        return false; 
    };
    if (result == PICO_ERROR_TIMEOUT) {
        printf("timeout in reading from temperature sensor\n"); 
        return false;
    } 

    upper_byte = buf[0];
    lower_byte = buf[1];

    //clears flag bits in upper byte
    temperature = mcp9808_convert_temp(upper_byte & 0x1F, lower_byte);
    //printf("PA temperature: %.4f°C\n", temperature);
    pa_temparature = (temperature > 0.0) ? (uint16_t)(temperature + 0.5) : (uint16_t)(temperature - 0.5);
    //printf("PA temperature: %d°C\n", pa_temparature);

    return true;
}


/*  Define constants for MCP23008 I2C bus addresses
    This address is set by pulling the pins A0, A1, A2 up/high (to +3.3V) or down/low (to GND).
    addr  A2,A1,A0 =>   0x20  0, 0, 0
*/

#define MCP0_ADDR 0x20


// Define constants for MCP23008 register numbers.
#define IODIR   0x00
#define GPIO    0x09

// Define a constant for output
#define OUTPUT   0x00
#define ALL_HIGH 0xFF
#define ALL_LOW  0x00
                  
void initOutputs(void) {
  uint8_t buffer[2]; 

  buffer[0] = GPIO;
  buffer[1] = ALL_LOW;

  int result = i2c_write_blocking(i2c1, MCP0_ADDR, buffer, 2, false); 
  DEBUG_printf("Result init I2C IO extender (Ok > 0) = %x\n", result);
}

int mcp_init(void) {

    i2c_init(i2c1, 400 * 1000);
    gpio_set_function(PICO_I2C0_SDA_PIN, GPIO_FUNC_I2C);
    gpio_set_function(PICO_I2C0_SCL_PIN, GPIO_FUNC_I2C);
    gpio_pull_up(PICO_I2C0_SDA_PIN);
    gpio_pull_up(PICO_I2C0_SCL_PIN);
    
    // printf("\nI2C Bus Scan for finding connected i2c devices\n");
    // printf("   0  1  2  3  4  5  6  7  8  9  A  B  C  D  E  F\n");

    // for (int addr = 0; addr < (1 << 7); ++addr) {
    //   if (addr % 16 == 0) {
    //     printf("%02x ", addr);
    //   }
    //   int ret;
    //   uint8_t rxdata;
    //   ret = i2c_read_blocking(i2c1, addr, &rxdata, 1, false);

    //   printf(ret < 0 ? "." : "@");
    //   printf(addr % 16 == 15 ? "\n" : "  ");
    // }


    // First, we must set the I/O direction to output. Write 0x00 to IODIR register.
    uint8_t buffer[2];
    buffer[0] = IODIR;
    buffer[1] = OUTPUT;
    if (i2c_write_blocking(i2c1, MCP0_ADDR, buffer, 2, false) ==  PICO_ERROR_GENERIC) DEBUG_printf("Error writing to IO extender\n");

    initOutputs();
}

void setIOExtenderLPF(int byte) {
    uint8_t buffer[2];
    buffer[0] = GPIO;
    buffer[1] = byte;
    if (i2c_write_blocking(i2c1, MCP0_ADDR, buffer, 2, false) ==  PICO_ERROR_GENERIC) DEBUG_printf("Error writing to IO extender\n");
}

 void execute_sequencer_switch_pa_on(void) {
    //sequencer
    if (actualAmpState == TX_OFF) {
        sleep_ms(15);
        gpio_put(RELAIS_PIN, 1);
        sleep_ms(15);
        gpio_put(BIAS_PIN, 1); 
        actualAmpState = TX_ON;
    }      
 }

 void execute_sequencer_switch_pa_off(void) {
    //sequencer
    if (actualAmpState == TX_ON) {
        sleep_ms(15);
        gpio_put(BIAS_PIN, 0);
        sleep_ms(15);
        gpio_put(RELAIS_PIN, 0);
        actualAmpState = TX_OFF;
    } 
 }

typedef struct TCP_SERVER_T_ {
    struct tcp_pcb *server_pcb;
    struct tcp_pcb *client_pcb;
    bool complete;
    uint8_t buffer_sent[BUF_SIZE];
    uint8_t buffer_recv[BUF_SIZE];
    int sent_len;
    int recv_len;
    int run_count;
} TCP_SERVER_T;

static TCP_SERVER_T* tcp_server_init(void) {
    TCP_SERVER_T *state = calloc(1, sizeof(TCP_SERVER_T));
    if (!state) {
        DEBUG_printf("failed to allocate state\n");
        return NULL;
    }
    return state;
}

static err_t tcp_server_close(void *arg) {
    TCP_SERVER_T *state = (TCP_SERVER_T*)arg;
    err_t err = ERR_OK;
    DEBUG_printf("Close TCP connection\n");
    if (state->client_pcb != NULL) {
        tcp_arg(state->client_pcb, NULL);
        //tcp_poll(state->client_pcb, NULL, 0);
        tcp_sent(state->client_pcb, NULL);
        tcp_recv(state->client_pcb, NULL);
        tcp_err(state->client_pcb, NULL);
        err = tcp_close(state->client_pcb);
        if (err != ERR_OK) {
            DEBUG_printf("close failed %d, calling abort\n", err);
            tcp_abort(state->client_pcb);
            err = ERR_ABRT;
        }
        state->client_pcb = NULL;
    }
    if (state->server_pcb) {
        tcp_arg(state->server_pcb, NULL);
        tcp_close(state->server_pcb);
        state->server_pcb = NULL;
    }
    return err;

}

static err_t tcp_server_result(void *arg, int status) {
    TCP_SERVER_T *state = (TCP_SERVER_T*)arg;
    if (status == 0) {
        DEBUG_printf("test success\n");
    } else {
        DEBUG_printf("test failed %d\n", status);
    }
    state->complete = true;
    return tcp_server_close(arg);
}

static err_t tcp_server_sent(void *arg, struct tcp_pcb *tpcb, u16_t len) {
    TCP_SERVER_T *state = (TCP_SERVER_T*)arg;
    //DEBUG_printf("tcp_server_sent %u\n", len);
    state->sent_len += len;

    if (state->sent_len >= BUF_SIZE) {
        // We should get the data back from the client
        state->recv_len = 0;
        //DEBUG_printf("Waiting for buffer from client\n");
    }
    return ERR_OK;
}

unsigned char reply[5] = {0x00, 0x00, 0xef, 0xfe, VERSION};  //calc at firmware => 0x01 = version 1/10 = 0.1

err_t tcp_server_send_data(void *arg, struct tcp_pcb *tpcb)
{
    TCP_SERVER_T *state = (TCP_SERVER_T*)arg;
    memcpy(state->buffer_sent, reply, 5);
    for(int i=5; i< BUF_SIZE; i++) {
        state->buffer_sent[i] = 0x0; 
    }
    // temperature
    if (pa_temp_measure_error) {
        state->buffer_sent[5] =  0xFF; //ERROR reading temperature; switch off tx mode.
        state->buffer_sent[6] =  0;
    } else {
        state->buffer_sent[5] =  0x00;
        state->buffer_sent[6] =  (pa_temparature & 0xFF); // temperature is N digit.
    }
    read_adc_values(); // not in loop for now.
    uint16_t forward = forward_adc_value;
    state->buffer_sent[7] = (forward >> 8) & 0xFF;  //msb
    state->buffer_sent[8] = forward & 0xFF; 
    uint16_t reverse = reverse_adc_value;
    state->buffer_sent[9] = (reverse >> 8) & 0xFF;  //msb
    state->buffer_sent[10] = reverse & 0xFF; 

    //DEBUG_printf("Forward voltage  %d\n", forward);
    //DEBUG_printf("Reverse voltage  %d\n", reverse);

    state->sent_len = 0;
    //DEBUG_printf("Writing %ld bytes to client\n", BUF_SIZE);

    err_t err = tcp_write(tpcb, state->buffer_sent, BUF_SIZE, TCP_WRITE_FLAG_COPY);
    if (err != ERR_OK) {
        DEBUG_printf("Failed to write data %d\n", err);
        //return tcp_server_result(arg, -12);
        return ERR_OK;
    }
    return ERR_OK;
}

err_t tcp_server_recv(void *arg, struct tcp_pcb *tpcb, struct pbuf *p, err_t err) {
    TCP_SERVER_T *state = (TCP_SERVER_T*)arg;
    if (!p) {
       // return tcp_server_result(arg, -13);
        return ERR_OK;
    }
    
    if (p->tot_len > 0) {
        //DEBUG_printf("tcp_server_recv %d/%d err %d\n", p->tot_len, state->recv_len, err);

        // Receive the buffer
        const uint16_t buffer_left = BUF_SIZE - state->recv_len;
        state->recv_len += pbuf_copy_partial(p, state->buffer_recv + state->recv_len,
                                             p->tot_len > buffer_left ? buffer_left : p->tot_len, 0);
        tcp_recved(tpcb, p->tot_len);
    }
    pbuf_free(p);

    if (state->recv_len == BUF_SIZE) {
        //DEBUG_printf("tcp_server_recv buffer ok\n");

        uint32_t code;
        memcpy(&code, state->buffer_recv, 4);
        //DEBUG_printf("code = %x\n", code);
        switch (code)
        {
            default:
                {
                    DEBUG_printf("message not for PA controller\n");
                    for(int i=0; i< BUF_SIZE; i++) {
                            DEBUG_printf("%x-", state->buffer_recv[i]);
                    }
                    DEBUG_printf("\n");
                }
                break;
            case 0xfeef0000:
                {
                    //DEBUG_printf("message for PA controller\n");
                    //for(int i=0; i< BUF_SIZE; i++) {
                            //DEBUG_printf("%x-", state->buffer_recv[i]);
                    //}
                    //DEBUG_printf("\n");
                    deviceState = convertToPowerState(state->buffer_recv[4]);
                    if (deviceState == ACTIVE) DEBUG_printf("PA Controller active \n"); else DEBUG_printf("PA Controller not active / standby\n");
                    pttState = convertToPTTState(state->buffer_recv[5]);
                    if (pttState == PA_ON) DEBUG_printf("PTT on \n"); else DEBUG_printf("PTT off\n");
                    lpfFilter = convertToLPFFilter(state->buffer_recv[6]);
                    //DEBUG_printf("LPF is set to %x \n", lpfFilter);
                }
                break;
        }
        // sending in answer.
        return tcp_server_send_data(arg, state->client_pcb);
    }
    return ERR_OK;
}

static err_t tcp_server_poll(void *arg, struct tcp_pcb *tpcb) {
    DEBUG_printf("tcp_server_poll_fn\n");
    return tcp_server_result(arg, -10); // no response is an error?
}

static void tcp_server_err(void *arg, err_t err) {
    if (err != ERR_ABRT) {
        DEBUG_printf("tcp_client_err_fn %d\n", err);
        tcp_server_result(arg, err);
    }
}

static err_t tcp_server_accept(void *arg, struct tcp_pcb *client_pcb, err_t err) {
    TCP_SERVER_T *state = (TCP_SERVER_T*)arg;
    if (err != ERR_OK || client_pcb == NULL) {
        DEBUG_printf("Failure in accept\n");
        tcp_server_result(arg, err);
        return ERR_VAL;
    }
    DEBUG_printf("Client connected\n");

    state->client_pcb = client_pcb;
    tcp_arg(client_pcb, state);
    tcp_sent(client_pcb, tcp_server_sent);
    tcp_recv(client_pcb, tcp_server_recv);
    //tcp_poll(client_pcb, tcp_server_poll, POLL_TIME_S * 2);
    
    
    tcp_err(client_pcb, tcp_server_err);

    //return tcp_server_send_data(arg, state->client_pcb);
    
    return ERR_OK;
}

static bool tcp_server_open(void *arg) {
    TCP_SERVER_T *state = (TCP_SERVER_T*)arg;
    DEBUG_printf("Starting server at %s on port %u\n", ip4addr_ntoa(netif_ip4_addr(netif_list)), TCP_PORT);

    struct tcp_pcb *pcb = tcp_new_ip_type(IPADDR_TYPE_ANY);
    if (!pcb) {
        DEBUG_printf("failed to create pcb\n");
        return false;
    }

    err_t err = tcp_bind(pcb, NULL, TCP_PORT);
    if (err) {
        DEBUG_printf("failed to bind to port %u\n", TCP_PORT);
        return false;
    }

    state->server_pcb = tcp_listen_with_backlog(pcb, 1);
    if (!state->server_pcb) {
        DEBUG_printf("failed to listen\n");
        if (pcb) {
            tcp_close(pcb);
        }
        return false;
    }

    tcp_arg(state->server_pcb, state);
    tcp_accept(state->server_pcb, tcp_server_accept);

    return true;
}

void run_tcp_server(void) {
    int blink_toggle = 0;

    TCP_SERVER_T *state = tcp_server_init();
    if (!state) {
        return;
    }
    if (!tcp_server_open(state)) {
        tcp_server_result(state, -11);
        return;
    }

    // Initialize PWM slice 0 on GPIO pin 1
    gpio_set_function(1, GPIO_FUNC_PWM);
    uint slice_num = pwm_gpio_to_slice_num(1); // get slice for pin 1.

    // Set PWM frequency and duty cycle
    pwm_config config = pwm_get_default_config();
    // Set the PWM frequency to 30 kHz
    pwm_config_set_clkdiv(&config, 4); // Pico runs at 125 MHz (5 is for 25KHz // 6 for 20KHz)
    pwm_init(slice_num, &config, true);

    uint16_t pwm_level = pwm_hw->slice[slice_num].top;
    //DEBUG_printf("PWM max level  %d \n", pwm_level);
   
    //while(!state->complete) {
    while(true) {
        sleep_ms(1);

        //set LED pin indication device state.
        blink_toggle++;
        if (blink_toggle > 1000) blink_toggle = 0;
        (deviceState == OFF) ? gpio_put(LED_PIN, 0) :  (deviceState == STANDBY) ? (blink_toggle > 500) ? gpio_put(LED_PIN, 0) : gpio_put(LED_PIN, 1) : (deviceState == ACTIVE) ? gpio_put(LED_PIN, 1): blink_toggle++;

        if (actualAmpState == TX_OFF)  setIOExtenderLPF(lpfFilter); // only setting filters via IO extender;  if not in TX mode.

        // if the temperature could not be deterimined do switch PTT off.
        if (!mcp9808_readtemperature()) {
            pa_temp_measure_error = true;   
            execute_sequencer_switch_pa_off();
        } else {
            pa_temp_measure_error = false;
            if (pttState == PA_ON ) execute_sequencer_switch_pa_on();
            if (pttState == PA_OFF ) execute_sequencer_switch_pa_off();
        }
        // Calculate PWM level based on temperature to set the FAN; in case of temp reading error => FAN max.
        uint16_t pwm_level = ( (pa_temparature > 25) || pa_temp_measure_error ) ? 65535 : 32767;
        pwm_set_gpio_level(1, pwm_level); 
    }
    free(state);
}

void netif_link_callback(struct netif *netif)
{
    printf("netif link status changed %s\n", netif_is_link_up(netif) ? "up" : "down");
}

void netif_status_callback(struct netif *netif)
{
    printf("netif status changed %s\n", ip4addr_ntoa(netif_ip4_addr(netif)));
}

int main() {
	// initialiseer IO
    gpio_init(BIAS_PIN);
    gpio_set_dir(BIAS_PIN, GPIO_OUT);
    gpio_put(BIAS_PIN, 0);
    gpio_init(RELAIS_PIN);
    gpio_set_dir(RELAIS_PIN, GPIO_OUT);
    gpio_put(RELAIS_PIN, 0);
	
    // LWIP network interface
    struct netif netif;

    struct netif_rmii_ethernet_config netif_config = {
        pio0, // PIO:            0
        0,    // pio SM:         0 and 1
        6,    // rx pin start:   6, 7, 8    => RX0, RX1, CRS
        10,   // tx pin start:   10, 11, 12 => TX0, TX1, TX-EN
        14,   // mdio pin start: 14, 15   => ?MDIO, MDC
        NULL, // MAC address (optional - NULL generates one based on flash id) 
    };

    // change the system clock to use the RMII reference clock from pin 20
    clock_configure_gpin(clk_sys, 20, 50 * MHZ, 50 * MHZ);
    sleep_ms(100);

    // initialize stdio after the clock change
    stdio_init_all();
    sleep_ms(5000);

    // initilize LWIP in NO SYS mode
    lwip_init();

    // initialize the PIO base RMII Ethernet network interface
    netif_rmii_ethernet_init(&netif, &netif_config);

    // Iam not usinf DHCP; i like a fixed IP address
    IP4_ADDR(&netif.ip_addr, 169, 254, 19, 101);
    IP4_ADDR(&netif.netmask, 255, 255, 0, 0);
    
    // assign callbacks for link and status
    netif_set_link_callback(&netif, netif_link_callback);
    netif_set_status_callback(&netif, netif_status_callback);

    // set the default interface and bring it up
    netif_set_default(&netif);
    netif_set_up(&netif);
    
    // setup core 1 to monitor the RMII ethernet interface
    // this let's core 0 do other things :)
    multicore_launch_core1(netif_rmii_ethernet_loop);

    httpd_init();

    // RP2040 LED ; Used as PTT indicator.
    gpio_init(LED_PIN);
    gpio_set_dir(LED_PIN, GPIO_OUT);
    gpio_put(LED_PIN, 0);

    // initialiseer IO
    gpio_init(BIAS_PIN);
    gpio_set_dir(BIAS_PIN, GPIO_OUT);
    gpio_put(BIAS_PIN, 0);
    gpio_init(RELAIS_PIN);
    gpio_set_dir(RELAIS_PIN, GPIO_OUT);
    gpio_put(RELAIS_PIN, 0);

    // initialiseer temperature sensor and IO extender.
    mcp9808_init(); 
    mcp_init();

    // initialiseer RP2040 ADC's
    adc_init();
    adc_gpio_init(26);  //ADC0
    adc_gpio_init(27);  //ADC1

    run_tcp_server();

    return 0;
}

//end of file.
